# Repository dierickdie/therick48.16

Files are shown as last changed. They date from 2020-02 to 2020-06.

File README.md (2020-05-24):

# therick48.16
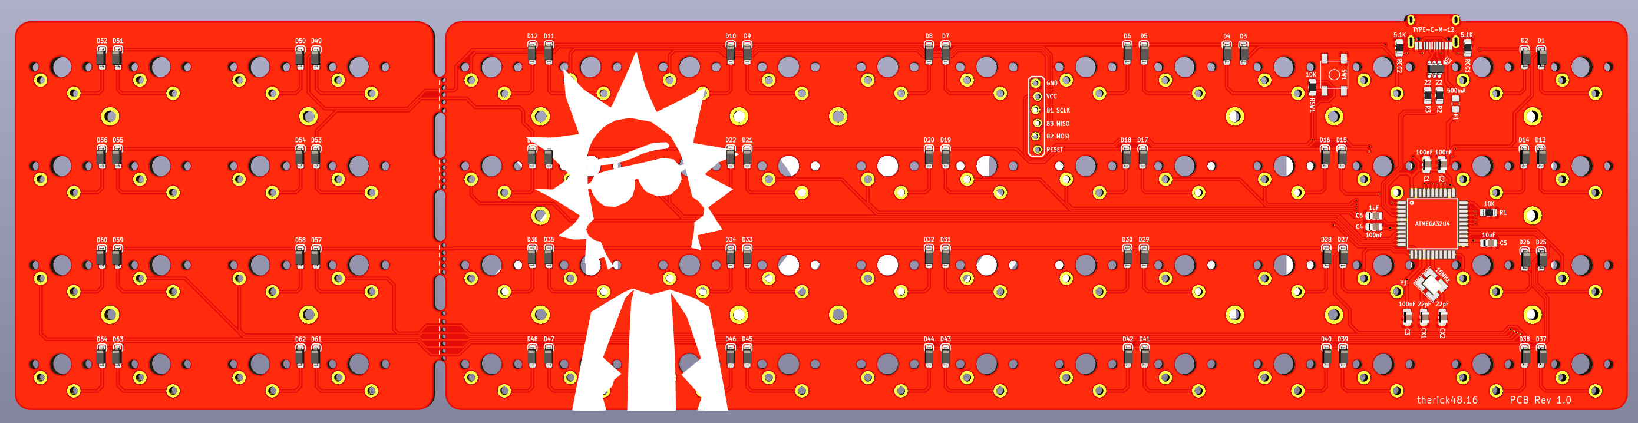
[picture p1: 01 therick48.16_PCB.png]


A 4x12 + 4x4 (48.16) ortho keyboard with USB C, SMD components, and 19mm spacing.

This is essentially a dumbed down Planck clone plus a numpad. The numpad is able to be snapped off to have just a 4x12.

If you want a southpaw numpad, look at the [therick48.16SP](https://github.com/therickthe/therick48.16SP). It uses the same firmware as this.

Although everything should<sup>(tm)</sup> work as is, it hasn't been physically tested.

**USE AT YOUR OWN RISK!!!** I am not responsible for any dumb things you do, fry your computer, break anything, etc.

## FAQ:
#### Does it have MIT/2x2u/etc.? 
No. Grid for life

#### Does it have backlighting?
No

#### Does it have RGB?
No

#### Does it have a rotary encoder?
No

#### Does it have hotswap?
No

#### Does it have Alps support?
No

#### Choc support?
No

#### Will you add any of these?
No

#### Why not?
I don't wanna

#### Will it fit a Planck case?
Yes! In theory. If you break off the numpad. Hasn't been tested.

#### Why USB C?
That's a dumb question

#### Will you add micro/mini/any USB other than type C?
No

#### Why not?
USB C is the future. Until a new standard comes out

#### But I don't have any USB C cables.
Boo hoo. I suggest building one. Zap Cables is a good place to get parts

#### Why is it named therick?
It started in fall of 2005 when I was just a boy. I started a new job, and needed a login name. The manager wrote The Rick (my first name is Rick). It has stuck ever since. Thanks, Sam! 64 is for 64 keys.

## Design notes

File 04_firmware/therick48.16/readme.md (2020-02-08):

A PCB I made for funsies

Make example for this keyboard (after setting up your build environment):  

    make therick:default

See [build environment setup](https://docs.qmk.fm/build_environment_setup.html) then the [make instructions](https://docs.qmk.fm/make_instructions.html) for more information.  
First pass at adding support for the 4x4 keyboard. Compiles but completely untested. Intended to kick-start development.

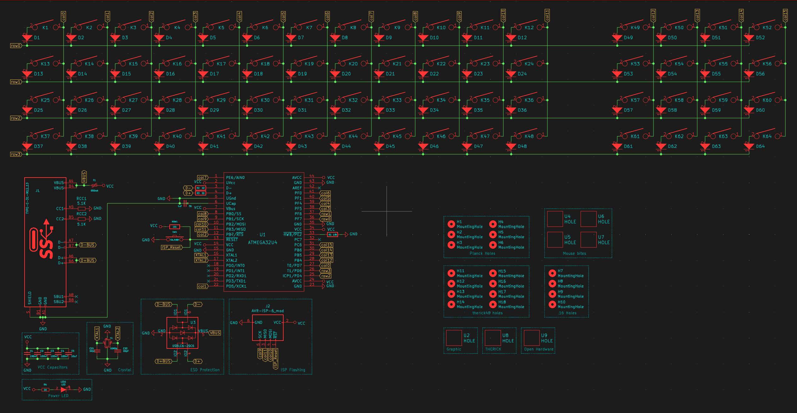
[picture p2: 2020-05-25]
04_Schematic.png

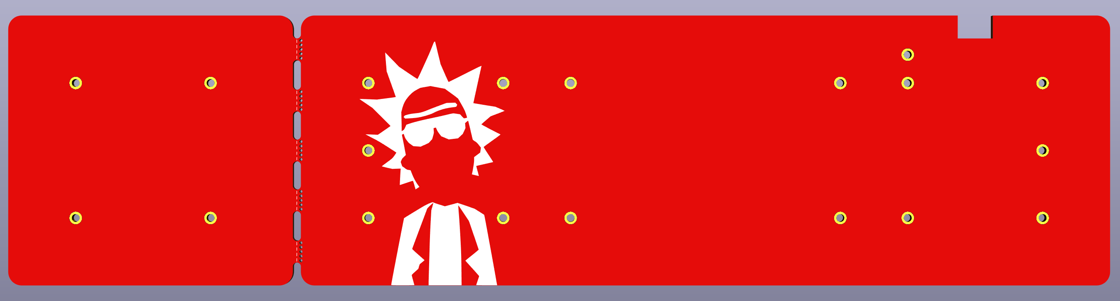
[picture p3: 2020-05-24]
03_therick48.16_bottom_plate.png

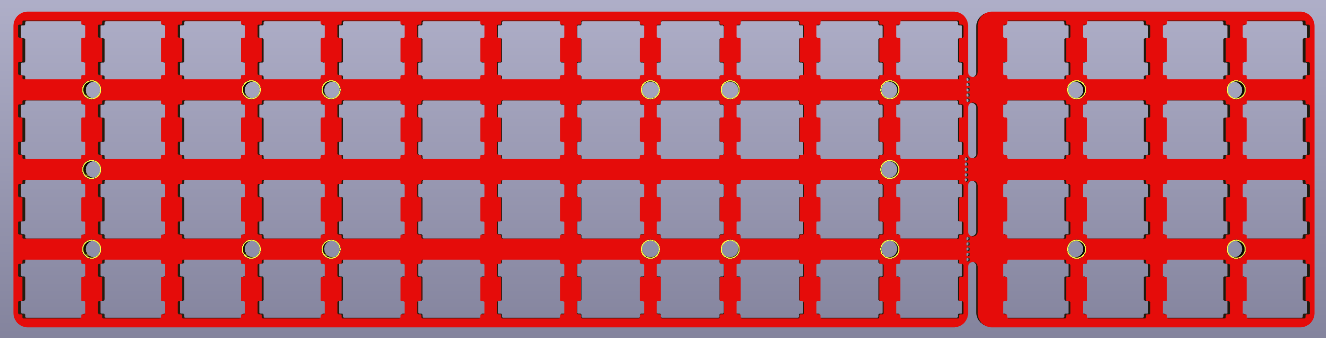
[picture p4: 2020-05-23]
02_therick48.16_top_plate.png

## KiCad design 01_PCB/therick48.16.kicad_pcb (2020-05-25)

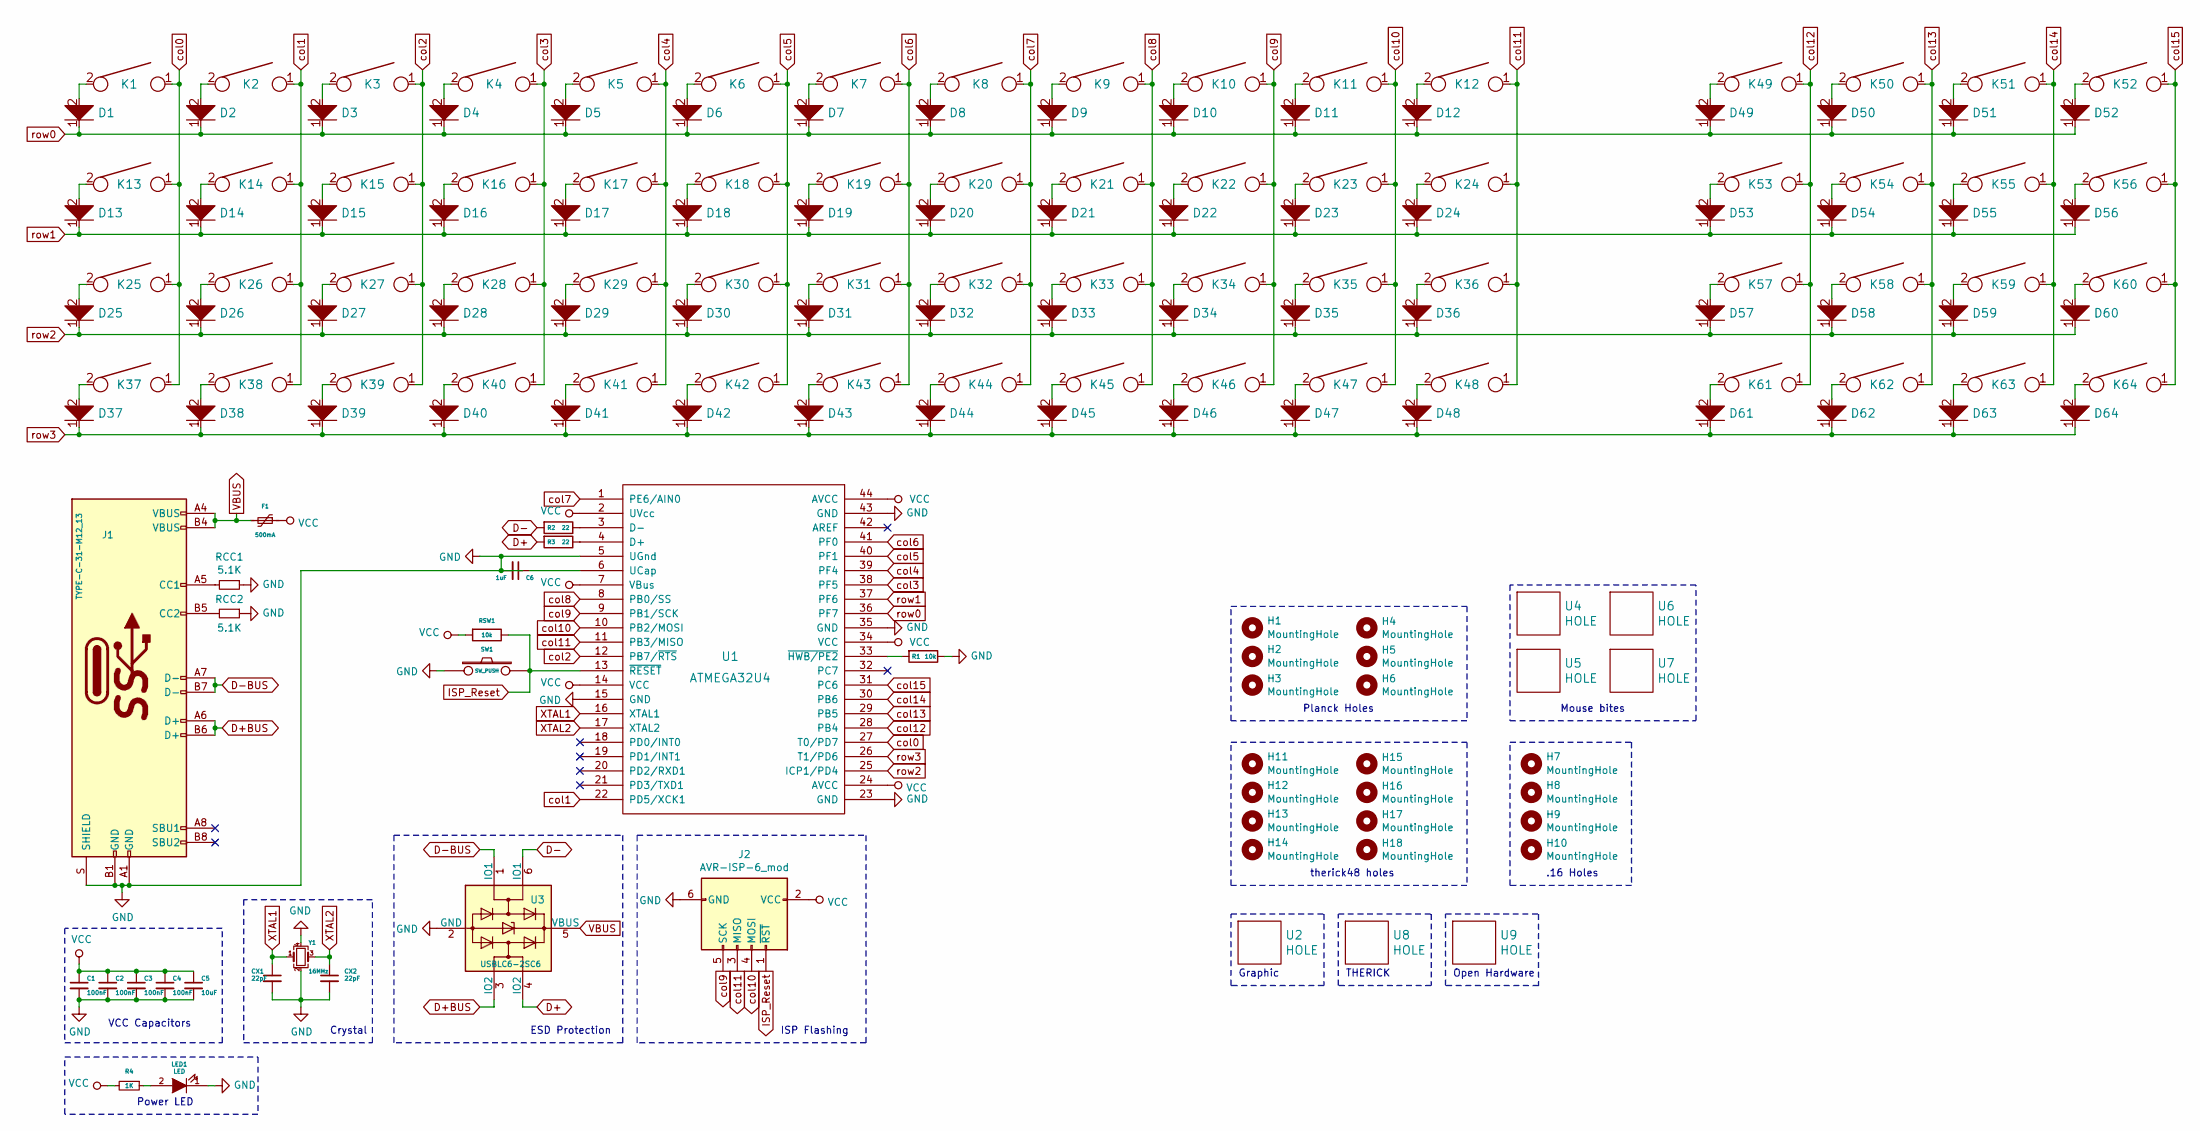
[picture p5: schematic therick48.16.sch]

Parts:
C1, C2, C3, C4: 100nF; C_0805_2012Metric_Pad1.15x1.40mm_HandSolder
C5: 10uF; C_0805_2012Metric_Pad1.15x1.40mm_HandSolder
C6: 1uF; C_0805_2012Metric_Pad1.15x1.40mm_HandSolder
CX1, CX2: 22pF; C_0805_2012Metric_Pad1.15x1.40mm_HandSolder
D1, D2, D3, D4, D5, D6, D7, D8, D9, D10, D11, D12, D13, D14, D15, D16, D17, D18, D19, D20, D21, D22, D23, D24, D25, D26, D27, D28, D29, D30, D31, D32, D33, D34, D35, D36, D37, D38, D39, D40, D41, D42, D43, D44, D45, D46, D47, D48, D49, D50, D51, D52, D53, D54, D55, D56, D57, D58, D59, D60, D61, D62, D63, D64: D; D_SOD-123_modified
F1: 500mA; Fuse_0805_2012Metric_Pad1.15x1.40mm_HandSolder
H1, H2, H3, H4, H5, H6, H7, H8, H9, H10, H11, H12, H13, H14, H15, H16, H17, H18: MountingHole; Generic-Mounthole
J1: TYPE-C-31-M12_13; TYPE-C-31-M-12
J2: AVR-ISP-6_mod; PIN_HEADER_1x6_OFFSET
K1, K2, K3, K4, K5, K6, K7, K8, K9, K10, K11, K12, K13, K14, K15, K16, K17, K18, K19, K20, K21, K22, K23, K24, K25, K26, K27, K28, K29, K30, K31, K32, K33, K34, K35, K36, K37, K38, K39, K40, K41, K42, K43, K44, K45, K46, K47, K48, K49, K50, K51, K52, K53, K54, K55, K56, K57, K58, K59, K60, K61, K62, K63, K64: KEYSW; MX100
LED1: LED; LED_0805_2012Metric_Pad1.15x1.40mm_HandSolder
R1: 10k; R_0805_2012Metric_Pad1.15x1.40mm_HandSolder
R2, R3: 22; R_0805_2012Metric_Pad1.15x1.40mm_HandSolder
R4: 1K; R_0805_2012Metric_Pad1.15x1.40mm_HandSolder
RCC1, RCC2: 5.1K; R_0805_2012Metric_Pad1.15x1.40mm_HandSolder
RSW1: 10k; R_0805_2012Metric_Pad1.15x1.40mm_HandSolder
SW1: SW_PUSH; SKQG-1155865
U1: ATMEGA32U4; ATMEGA32U4-AU
U2: HOLE; rick_large
U3: USBLC6-2SC6; SOT-23-6
U4, U5, U6, U7: HOLE; MouseBite_IPC7351
U8: HOLE; THERICK
U9: HOLE; OSHW-Logo2_9.8x8mm_SilkScreen
Y1: 16MHz; Crystal_SMD_3225-4Pin_3.2x2.5mm_HandSoldering

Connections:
D+: R3.2, U3.4 (IO2)
D+BUS: J1.A6 (D+), J1.B6 (D+), U3.3 (IO2)
D-: R2.2, U3.6 (IO1)
D-BUS: J1.A7 (D-), J1.B7 (D-), U3.1 (IO1)
GND: C1.2, C2.2, C3.2, C4.2, C5.2, C6.2, CX1.2, CX2.2, J1.A1 (GND), J1.B1 (GND), J1.S (SHIELD), J2.6 (GND), LED1.1 (K), R1.1, RCC1.1, RCC2.1, SW1.1, U1.5 (UGnd), U1.15 (GND), U1.23 (GND), U1.35 (GND), U1.43 (GND), U3.2 (GND), Y1.2, Y1.4
ISP_Reset: J2.1 (~RST), RSW1.1, SW1.2, U1.13 (~RESET)
unnamed: C6.1, U1.6 (UCap)
unnamed: D1.2, K1.2
unnamed: D2.2, K2.2
unnamed: D3.2, K3.2
unnamed: D4.2, K4.2
unnamed: D5.2, K5.2
unnamed: D6.2, K6.2
unnamed: D7.2, K7.2
unnamed: D8.2, K8.2
unnamed: D9.2, K9.2
unnamed: D10.2, K10.2
unnamed: D11.2, K11.2
unnamed: D12.2, K12.2
unnamed: D13.2, K13.2
unnamed: D14.2, K14.2
unnamed: D15.2, K15.2
unnamed: D16.2, K16.2
unnamed: D17.2, K17.2
unnamed: D18.2, K18.2
unnamed: D19.2, K19.2
unnamed: D20.2, K20.2
unnamed: D21.2, K21.2
unnamed: D22.2, K22.2
unnamed: D23.2, K23.2
unnamed: D24.2, K24.2
unnamed: D25.2, K25.2
unnamed: D26.2, K26.2
unnamed: D27.2, K27.2
unnamed: D28.2, K28.2
unnamed: D29.2, K29.2
unnamed: D30.2, K30.2
unnamed: D31.2, K31.2
unnamed: D32.2, K32.2
unnamed: D33.2, K33.2
unnamed: D34.2, K34.2
unnamed: D35.2, K35.2
unnamed: D36.2, K36.2
unnamed: D37.2, K37.2
unnamed: D38.2, K38.2
unnamed: D39.2, K39.2
unnamed: D40.2, K40.2
unnamed: D41.2, K41.2
unnamed: D42.2, K42.2
unnamed: D43.2, K43.2
unnamed: D44.2, K44.2
unnamed: D45.2, K45.2
unnamed: D46.2, K46.2
unnamed: D47.2, K47.2
unnamed: D48.2, K48.2
unnamed: D49.2, K49.2
unnamed: D50.2, K50.2
unnamed: D51.2, K51.2
unnamed: D52.2, K52.2
unnamed: D53.2, K53.2
unnamed: D54.2, K54.2
unnamed: D55.2, K55.2
unnamed: D56.2, K56.2
unnamed: D57.2, K57.2
unnamed: D58.2, K58.2
unnamed: D59.2, K59.2
unnamed: D60.2, K60.2
unnamed: D61.2, K61.2
unnamed: D62.2, K62.2
unnamed: D63.2, K63.2
unnamed: D64.2, K64.2
unnamed: J1.A5 (CC1), RCC1.2
unnamed: J1.B5 (CC2), RCC2.2
unnamed: LED1.2 (A), R4.1
unnamed: R1.2, U1.33 (~HWB/PE2)
unnamed: R2.1, U1.3 (D-)
unnamed: R3.1, U1.4 (D+)
VBUS: F1.2, J1.A4 (VBUS), J1.B4 (VBUS), U3.5 (VBUS)
VCC: C1.1, C2.1, C3.1, C4.1, C5.1, F1.1, J2.2 (VCC), R4.2, RSW1.2, U1.2 (UVcc), U1.7 (VBus), U1.14 (VCC), U1.24 (AVCC), U1.34 (VCC), U1.44 (AVCC)
XTAL1: CX1.1, U1.16 (XTAL1), Y1.1
XTAL2: CX2.1, U1.17 (XTAL2), Y1.3
col0: K1.1, K13.1, K25.1, K37.1, U1.27 (T0/PD7)
col1: K2.1, K14.1, K26.1, K38.1, U1.22 (PD5/XCK1)
col2: K3.1, K15.1, K27.1, K39.1, U1.12 (PB7/~RTS)
col3: K4.1, K16.1, K28.1, K40.1, U1.38 (PF5)
col4: K5.1, K17.1, K29.1, K41.1, U1.39 (PF4)
col5: K6.1, K18.1, K30.1, K42.1, U1.40 (PF1)
col6: K7.1, K19.1, K31.1, K43.1, U1.41 (PF0)
col7: K8.1, K20.1, K32.1, K44.1, U1.1 (PE6/AIN0)
col8: K9.1, K21.1, K33.1, K45.1, U1.8 (PB0/SS)
col9: J2.5 (SCK), K10.1, K22.1, K34.1, K46.1, U1.9 (PB1/SCK)
col10: J2.4 (MOSI), K11.1, K23.1, K35.1, K47.1, U1.10 (PB2/MOSI)
col11: J2.3 (MISO), K12.1, K24.1, K36.1, K48.1, U1.11 (PB3/MISO)
col12: K49.1, K53.1, K57.1, K61.1, U1.28 (PB4)
col13: K50.1, K54.1, K58.1, K62.1, U1.29 (PB5)
col14: K51.1, K55.1, K59.1, K63.1, U1.30 (PB6)
col15: K52.1, K56.1, K60.1, K64.1, U1.31 (PC6)
row0: D1.1, D2.1, D3.1, D4.1, D5.1, D6.1, D7.1, D8.1, D9.1, D10.1, D11.1, D12.1, D49.1, D50.1, D51.1, D52.1, U1.36 (PF7)
row1: D13.1, D14.1, D15.1, D16.1, D17.1, D18.1, D19.1, D20.1, D21.1, D22.1, D23.1, D24.1, D53.1, D54.1, D55.1, D56.1, U1.37 (PF6)
row2: D25.1, D26.1, D27.1, D28.1, D29.1, D30.1, D31.1, D32.1, D33.1, D34.1, D35.1, D36.1, D57.1, D58.1, D59.1, D60.1, U1.25 (ICP1/PD4)
row3: D37.1, D38.1, D39.1, D40.1, D41.1, D42.1, D43.1, D44.1, D45.1, D46.1, D47.1, D48.1, D61.1, D62.1, D63.1, D64.1, U1.26 (T1/PD6)

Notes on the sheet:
VCC Capacitors
Planck Holes
Graphic
Crystal
ESD Protection
ISP Flashing
.16 Holes
therick48 holes
THERICK
Power LED
Open Hardware
Mouse bites

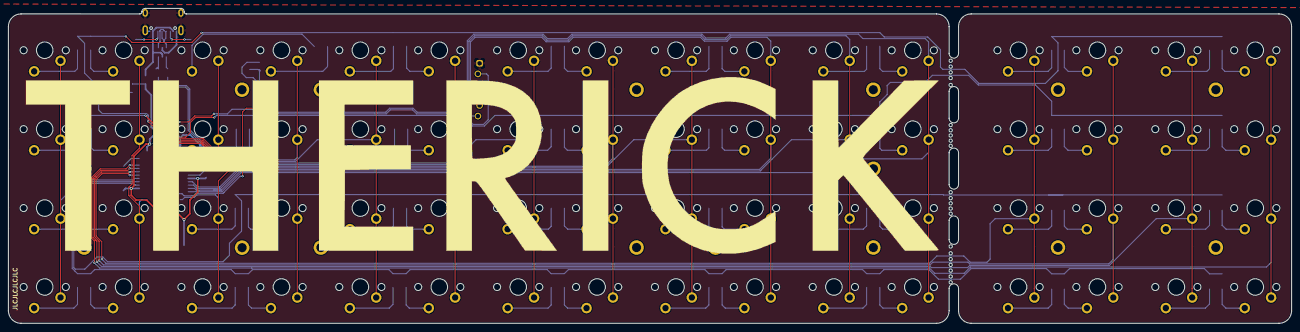
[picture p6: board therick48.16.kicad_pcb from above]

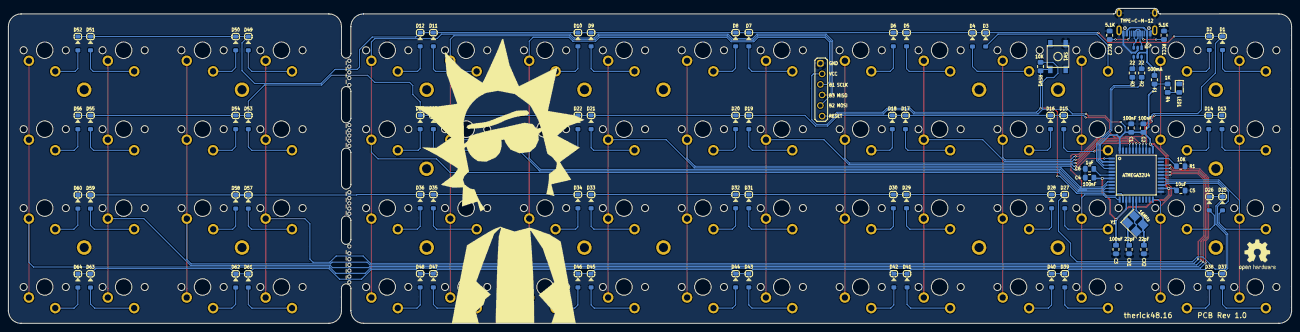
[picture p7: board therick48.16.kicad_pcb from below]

Board: 2 copper layers, 308.9 x 75.8 mm, 176 parts (89 on the bottom side), 101 nets.

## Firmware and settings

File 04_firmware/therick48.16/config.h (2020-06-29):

#pragma once

#include "config_common.h"

/* USB Device descriptor parameter */
#define VENDOR_ID       0xFEED
#define PRODUCT_ID      0x0001
#define DEVICE_VER      0x0001
#define MANUFACTURER    therick
#define PRODUCT         therick64BA
#define DESCRIPTION     Blatant copy of Planck with numpad

/* key matrix size */
#define MATRIX_ROWS 4
#define MATRIX_COLS 16

/*
 * Keyboard Matrix Assignments
 *
 * Change this to how you wired your keyboard
 * COLS: AVR pins used for columns, left to right
 * ROWS: AVR pins used for rows, top to bottom
 * DIODE_DIRECTION: COL2ROW = COL = Anode (+), ROW = Cathode (-, marked on diode)
 *                  ROW2COL = ROW = Anode (+), COL = Cathode (-, marked on diode)
 *
*/

#define MATRIX_ROW_PINS { F7, F6, D4, D6 }
#define MATRIX_COL_PINS { D7, D5, B7, F5, F4, F1, F0, E6, B0, B1, B2, B3, B4, B5, B6, C6 }
#define UNUSED_PINS


/* COL2ROW, ROW2COL, or CUSTOM_MATRIX */
#define DIODE_DIRECTION COL2ROW

// #define BACKLIGHT_PIN C7
// #define BACKLIGHT_BREATHING
// #define BACKLIGHT_LEVELS 3


/* Debounce reduces chatter (unintended double-presses) - set 0 if debouncing is not needed */
#define DEBOUNCING_DELAY 5

/* encoder support */
#define ENCODERS_PAD_A { D3 }
#define ENCODERS_PAD_B { D2 }

#define ENCODER_RESOLUTION 4

/* define if matrix has ghost (lacks anti-ghosting diodes) */
//#define MATRIX_HAS_GHOST

/* number of backlight levels */

/* Mechanical locking support. Use KC_LCAP, KC_LNUM or KC_LSCR instead in keymap */
#define LOCKING_SUPPORT_ENABLE
/* Locking resynchronize hack */
#define LOCKING_RESYNC_ENABLE

/* If defined, GRAVE_ESC will always act as ESC when CTRL is held.
 * This is userful for the Windows task manager shortcut (ctrl+shift+esc).
 */
// #define GRAVE_ESC_CTRL_OVERRIDE

/*
 * Force NKRO
 *
 * Force NKRO (nKey Rollover) to be enabled by default, regardless of the saved
 * state in the bootmagic EEPROM settings. (Note that NKRO must be enabled in the
 * makefile for this to work.)
 *
 * If forced on, NKRO can be disabled via magic key (default = LShift+RShift+N)
 * until the next keyboard reset.
 *
 * NKRO may prevent your keystrokes from being detected in the BIOS, but it is
 * fully operational during normal computer usage.
 *
 * For a less heavy-handed approach, enable NKRO via magic key (LShift+RShift+N)
 * or via bootmagic (hold SPACE+N while plugging in the keyboard). Once set by
 * bootmagic, NKRO mode will always be enabled until it is toggled again during a
 * power-up.
 *
 */
//#define FORCE_NKRO

/*
 * Magic Key Options
 *
 * Magic keys are hotkey commands that allow control over firmware functions of
 * the keyboard. They are best used in combination with the HID Listen program,
 * found here: https://www.pjrc.com/teensy/hid_listen.html
 *
 * The options below allow the magic key functionality to be changed. This is
 * useful if your keyboard/keypad is missing keys and you want magic key support.
 *
 */

/* key combination for magic key command */
#define IS_COMMAND() ( \
    keyboard_report->mods == (MOD_BIT(KC_LSHIFT) | MOD_BIT(KC_RSHIFT)) \
)

/* control how magic key switches layers */
//#define MAGIC_KEY_SWITCH_LAYER_WITH_FKEYS  true
//#define MAGIC_KEY_SWITCH_LAYER_WITH_NKEYS  true
//#define MAGIC_KEY_SWITCH_LAYER_WITH_CUSTOM false

/* override magic key keymap */
//#define MAGIC_KEY_SWITCH_LAYER_WITH_FKEYS
//#define MAGIC_KEY_SWITCH_LAYER_WITH_NKEYS
//#define MAGIC_KEY_SWITCH_LAYER_WITH_CUSTOM
//#define MAGIC_KEY_HELP1          H
//#define MAGIC_KEY_HELP2          SLASH
//#define MAGIC_KEY_DEBUG          D
//#define MAGIC_KEY_DEBUG_MATRIX   X
//#define MAGIC_KEY_DEBUG_KBD      K
//#define MAGIC_KEY_DEBUG_MOUSE    M
//#define MAGIC_KEY_VERSION        V
//#define MAGIC_KEY_STATUS         S
//#define MAGIC_KEY_CONSOLE        C
//#define MAGIC_KEY_LAYER0_ALT1    ESC
//#define MAGIC_KEY_LAYER0_ALT2    GRAVE
//#define MAGIC_KEY_LAYER0         0
//#define MAGIC_KEY_LAYER1         1
//#define MAGIC_KEY_LAYER2         2
//#define MAGIC_KEY_LAYER3         3
//#define MAGIC_KEY_LAYER4         4
//#define MAGIC_KEY_LAYER5         5
//#define MAGIC_KEY_LAYER6         6
//#define MAGIC_KEY_LAYER7         7
//#define MAGIC_KEY_LAYER8         8
//#define MAGIC_KEY_LAYER9         9
//#define MAGIC_KEY_BOOTLOADER     PAUSE
//#define MAGIC_KEY_LOCK           CAPS
//#define MAGIC_KEY_EEPROM         E
//#define MAGIC_KEY_NKRO           N
//#define MAGIC_KEY_SLEEP_LED      Z

/*
 * Feature disable options
 *  These options are also useful to firmware size reduction.
 */

/* disable debug print */
//#define NO_DEBUG

/* disable print */
//#define NO_PRINT

/* disable action features */
//#define NO_ACTION_LAYER
//#define NO_ACTION_TAPPING
//#define NO_ACTION_ONESHOT
//#define NO_ACTION_MACRO
//#define NO_ACTION_FUNCTION

/*
 * MIDI options
 */

/* Prevent use of disabled MIDI features in the keymap */
//#define MIDI_ENABLE_STRICT 1

/* enable basic MIDI features:
   - MIDI notes can be sent when in Music mode is on
*/
//#define MIDI_BASIC
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

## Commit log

2020-01-25 Cleanup Schematic
    [therick64BA-B_Cu.gbr, therick64BA-B_Mask.gbr, therick64BA-B_Paste.gbr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]
2020-02-07 Update to 19mm
    [therick64BA-B_Cu.gbr, therick64BA-B_Mask.gbr, therick64BA-B_Paste.gbr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]
2020-02-08 Update some routing
    [therick64BA.kicad_pcb]
2020-02-08 Align Switches
    [therick64BA.kicad_pcb]
2020-02-23 Changed pins to make routing cleaner
    [therick64BA-B_Cu.gbr, therick64BA-B_Mask.gbr, therick64BA-B_Paste.gbr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]
2020-05-23 Renamed files, made gap between 4x12 and 4x4 .25 inches
    [therick48.16-B_Cu.gbr, therick48.16-B_Mask.gbr, therick48.16-B_Paste.gbr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]
2020-05-23 Changed a trace
    [therick48.16-B_Cu.gbr, therick48.16-B_Mask.gbr, therick48.16-B_Paste.gbr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]
2020-05-24 48+16 to 48.16
    [therick48.16-B_Cu.gbr, therick48.16-B_Mask.gbr, therick48.16-B_Paste.gbr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]
2020-05-24 Rename folders
    [therick48.16-B_Cu.gbr, therick48.16-B_Mask.gbr, therick48.16-B_Paste.gbr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]
2020-05-24 Update 04 Schematic.png
    [therick48.16.sch]
2020-05-24 Add reset hole to bottom plate
    [therick48.16_bottom_plate-B_Cu.gbr, therick48.16_bottom_plate-B_Mask.gbr, therick48.16_bottom_plate-B_Paste.gbr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]
2020-05-25 Add Power LED
    [therick48.16.kicad_pcb, therick48.16.sch]
2020-05-30 New Gerber files
    [therick48.16-B_Cu.gbr, therick48.16-B_Mask.gbr, therick48.16-B_Paste.gbr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]
2020-06-06 Update Gerber
    [therick48.16-B_Cu.gbr, therick48.16-B_Mask.gbr, therick48.16-B_Paste.gbr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]
2020-06-29 Update gerber, keymap.c
    [therick48.16-B_Cu.gbr, therick48.16-B_Mask.gbr, therick48.16-B_Paste.gbr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]
